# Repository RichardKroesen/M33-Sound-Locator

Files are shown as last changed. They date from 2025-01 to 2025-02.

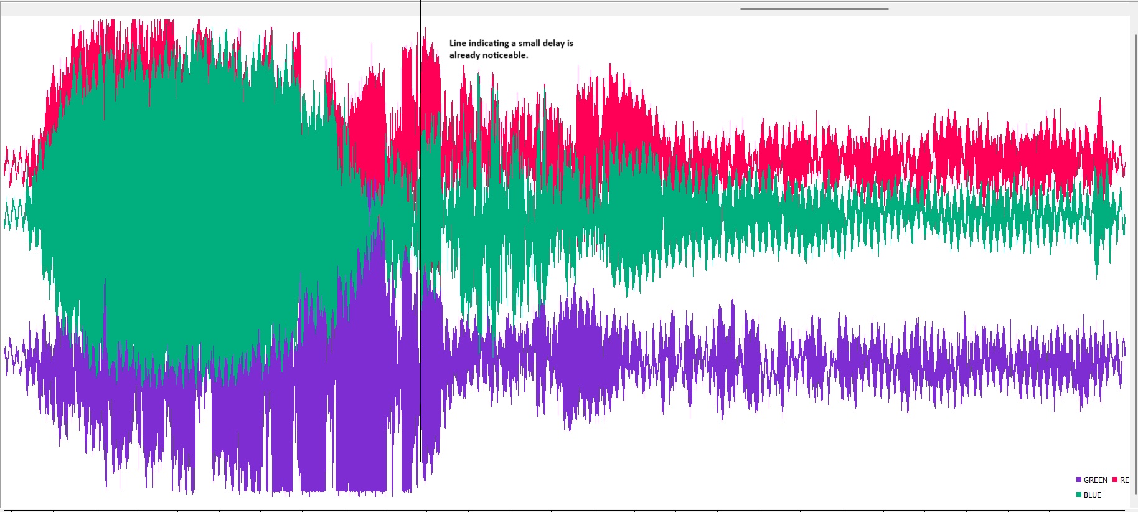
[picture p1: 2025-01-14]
docs/functional_testing/Delay_principle_verification.jpg

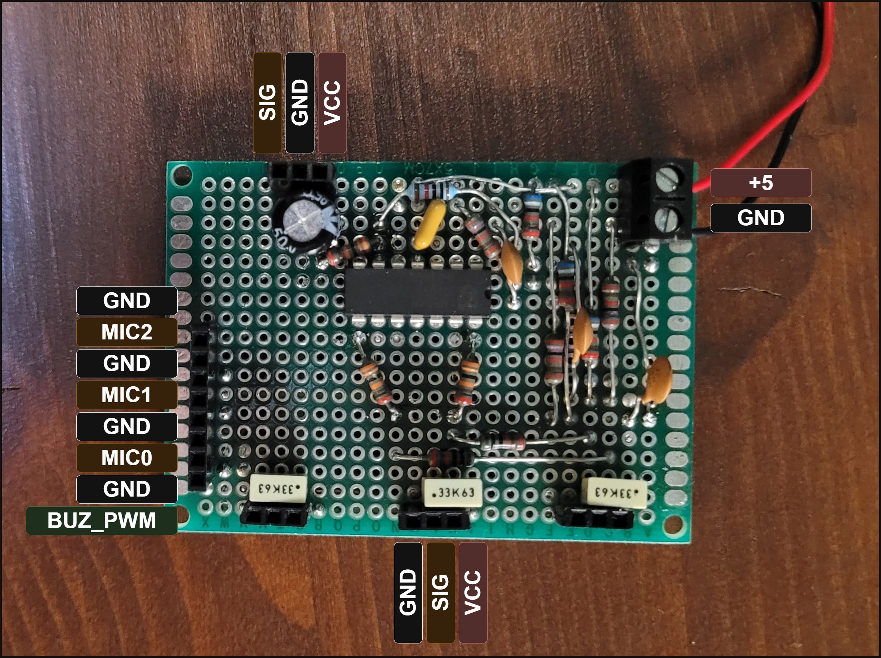
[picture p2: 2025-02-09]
docs/v1.0-PCB_pinout.jpg

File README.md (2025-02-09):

# Sound Locator M33 
This project has an educational purpose in the context of Digital Signal Processing & Control Systems. It is part of the Linear Systems (5LIU0)course at Technical University Eindhoven (TUe).

*The project's problem definition is*: 
> The challenge lies in accurately localizing a sound source on a two-dimensional plane
in real-time using audio pulses of a predefined frequency.
This involves addressing limitations in real-time processing, noise interference, and
the computational constraints of embedded systems while designing and implementing an effective DSP algorithm.

In more practical sense, it's a real-time processing system which locates the buzzer on a 2D plane. 

## Getting Started
**Clone by**: 

``git clone --recurse-submodules git@github.com:RichardKroesen/M33-Sound-Locator.git``

**Building Steps**: 
- mkdir build
- cmake ..
- make -j4

**Flashing steps**
Make sure the device is in BOOTSEL mode, this can be done by pressing the BOOTSEL button on the Pico. Afterwards there are two methods of uploading the file:

1. Using file explorer

Simply use a file explorer to drag the .uf2 file into the memory of the pico.

2. Using picotool

It is also possible to flash the device using picotool, type the command down below to flash using the picotool. This command assumes you are in the root of the project. NOT in the build folder!

`picotool load -u -v -x -t elf build/src/LINEAR_SYSTEMS.elf`

## Prerequisites 
For proper usage of this repository the following things are needed: 
- CMake
- PicoSDK (if it is not properly automatically build with CMake configuration).
- Arm GCC Compiler: [download page](https://developer.arm.com/downloads/-/gnu-rm)
- libusb [download page](https://libusb.info/)
- For debugging J-Link: [weblink](https://www.segger.com/downloads/jlink/) 
 
Or use on Linux the following command:
`sudo apt install cmake python3 g++ build-essential ninja-build`
installing the Arm GCC compiler (the hard way)
1) ```wget https://developer.arm.com/-/media/Files/downloads/gnu/14.2.rel1/binrel/arm-gnu-toolchain-14.2.rel1-x86_64-arm-none-eabi.tar.xz```
2) ```tar -xvf arm-gnu-toolchain-14.2.rel1-x86_64-arm-none-eabi.tar.xz```
3) Move to a common location: ```sudo mv arm-gnu-toolchain-14.2.rel1-x86_64-arm-none-eabi /opt/```
4) Add to path: ```export PATH=$PATH:/opt/arm-gnu-toolchain-14.2.rel1-x86_64-arm-none-eabi/bin```
5) For Pico SDK: ```export PICO_TOOLCHAIN_PATH=/opt/arm-gnu-toolchain-14.2.rel1-x86_64-arm-none-eabi``` and ```export PATH=$PICO_TOOLCHAIN_PATH/bin:$PATH```

## Troubleshooting 
Since in our project group everyone is working on a different system there could be some compilation issues. In this section the most common issues are documented for quick reference. 

- CMake Error at build/_deps/pico_sdk-src/cmake/preload/toolchains/util/find_compiler.cmake:29 (message):
  Compiler 'arm-none-eabi-gcc' not found, you can specify search path with
  "PICO_TOOLCHAIN_PATH". ==> Repeating step 5 seems to fix this issue. 

After you cloned load the submodules properly:
``git submodule update --init`` 

## Project state
This repository contains the development and implementation of a real-time sound source localization system. The project integrates signal processing, embedded systems, and hardware design for accurate 2D localization.

Current version is contains an embedded codebase which is used as data logging acquisition. And then manually feeding these logs into model scripts so that system evaluation is feasible. The intent is to finalize this project someday as a hobby, but for now it is released for the course finalization. 

### Finalization Steps
- Implement TDOA algorithm on the embedded device => Python model conversion
- Integrate key signal processing features:
  - Target signal validation
  - Time Difference of Arrival (TDOA) estimation
  - Final system testing
- Produce a refined PCB design with:
  - Active bandpass filter
  - Variable amplifier
  - Stable reference voltage and improved grounding

### Lessons Learned
- Peak-based TDOA derivation is unreliable.
- Buzzers produce unsuitable waveforms for processing.
- Batch sampling introduces artifacts affecting analysis.
- Data transmission adds timing constraints but is irrelevant in a fully embedded system.

### Solutions Provided
- Designed PCB with anti-aliasing filter and amplifier.
- Developed real-time ADC DMA-based batch sampling (FreeRTOS).
- Implemented cross-correlation-based TDOA estimation.
- Achieved millimeter-precision real-time localization.
- Optimized target sound source detection using CMSIS-DSP.
- Provided insights for future improvements and finalization.

### Optimalization 
- Remove virtual interface implementation, which really not optimal and determinalistic approach. But it made prototyping convenient, the recommendation is to introduce curiously recurring template design pattern (CRTP), which makes polymorphism more determinalistic than currently. 
- For an even more enhancement dual-core functionally could be utilized for handling the ADC DMA on one core and the processing on the other. 
- ADC DMA logging and control is currently not efficient, since ASCII characters are send over instead of raw bytes. Besides the fact that the ADC also is blocked for around 20 ms (calculations are in our project report under appendix 1) before it can continue (we decided to keep it like this for simplicity and it worked well enough for our experimentation purpose). 

## Acknowledgements 
It is only fair to credit resources which inspired or gave an excellent example which already existed.

Our cmake FreeRTOS configuration is inspired by Dr. Jon Durrant, from [this repository](https://github.com/jondurrant/RPIPicoFreeRTOSSMPExp). 

Besides the Raspberry Pi Pico repository of FreeRTOS porting helped out, especially for RP2350 there were some troubles which are already described in the issues-list.

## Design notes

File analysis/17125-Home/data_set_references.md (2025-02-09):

batch_buffer_size = 600 samples, so each channel takes 600 samples before DMA IRQ. 
F sampling = 500 kHz => 500k/3 for each channel 

Buzzer tone = 4000 hz
Buzzer volume: 40 % duty 
Buzzer width: 100 ms

Build: release commit: buzzer branch

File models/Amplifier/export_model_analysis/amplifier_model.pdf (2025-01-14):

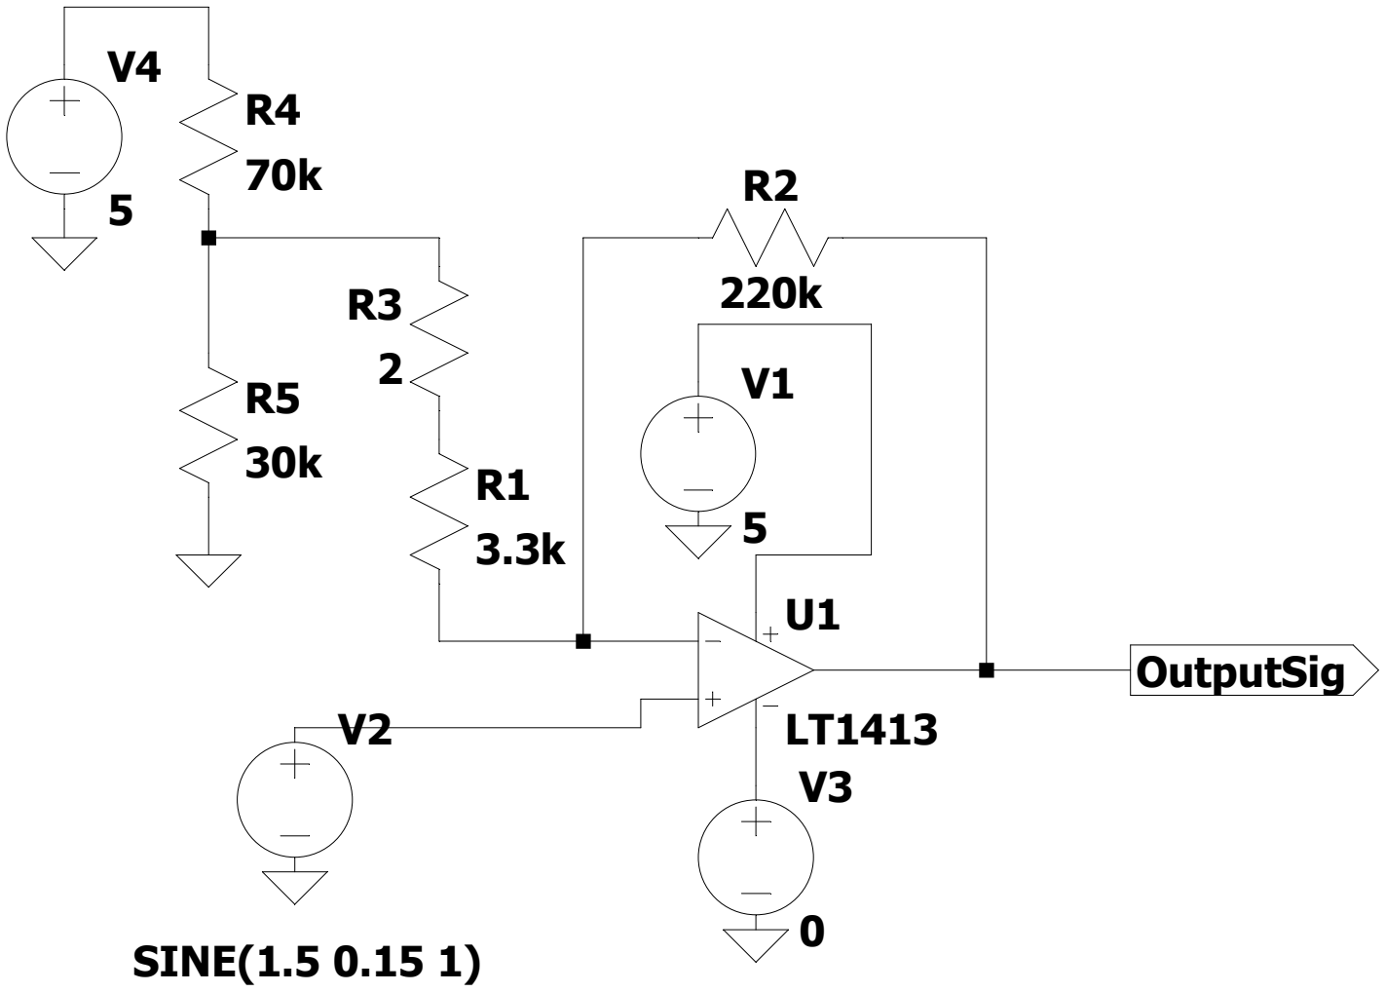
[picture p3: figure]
SINE(1.5 0.15 1); OutputSig

.tran 10

--- C:\_2025-Dev\2-Hardware\AmplifierModel.asc ---

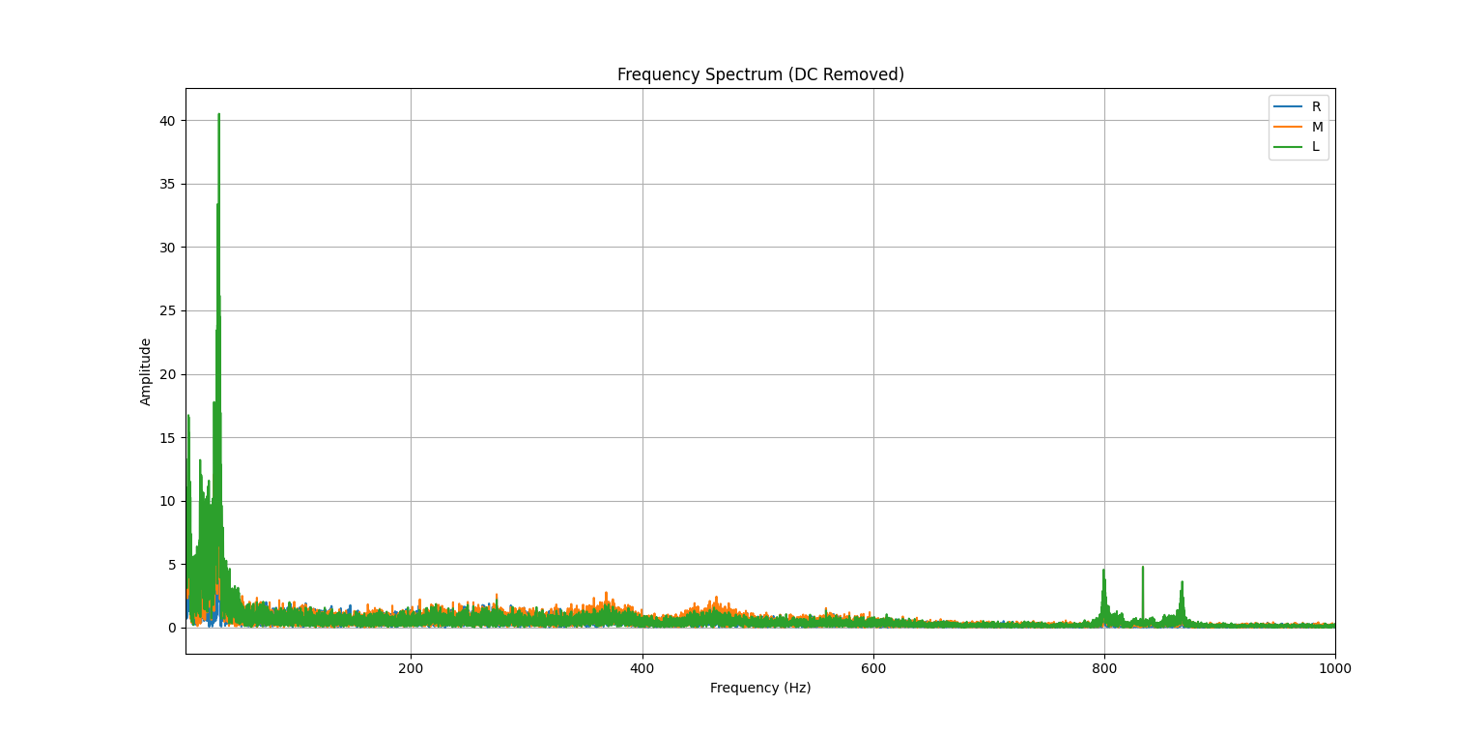
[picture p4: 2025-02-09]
analysis/insights/NoiseSpectrum.png

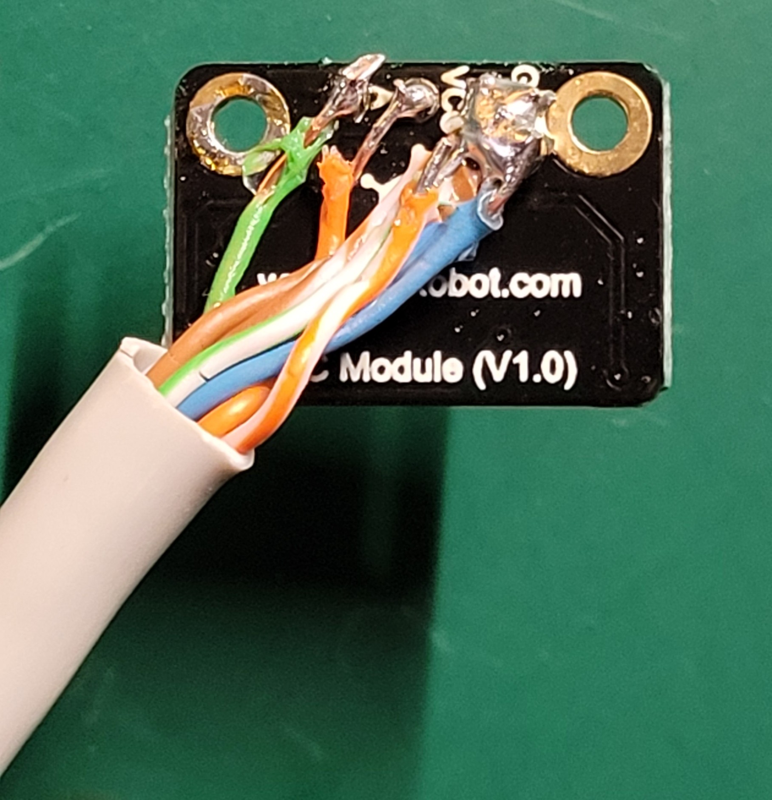
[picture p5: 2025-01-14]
electrical-mechnical-rsc/microphone-connection_pinout.jpg

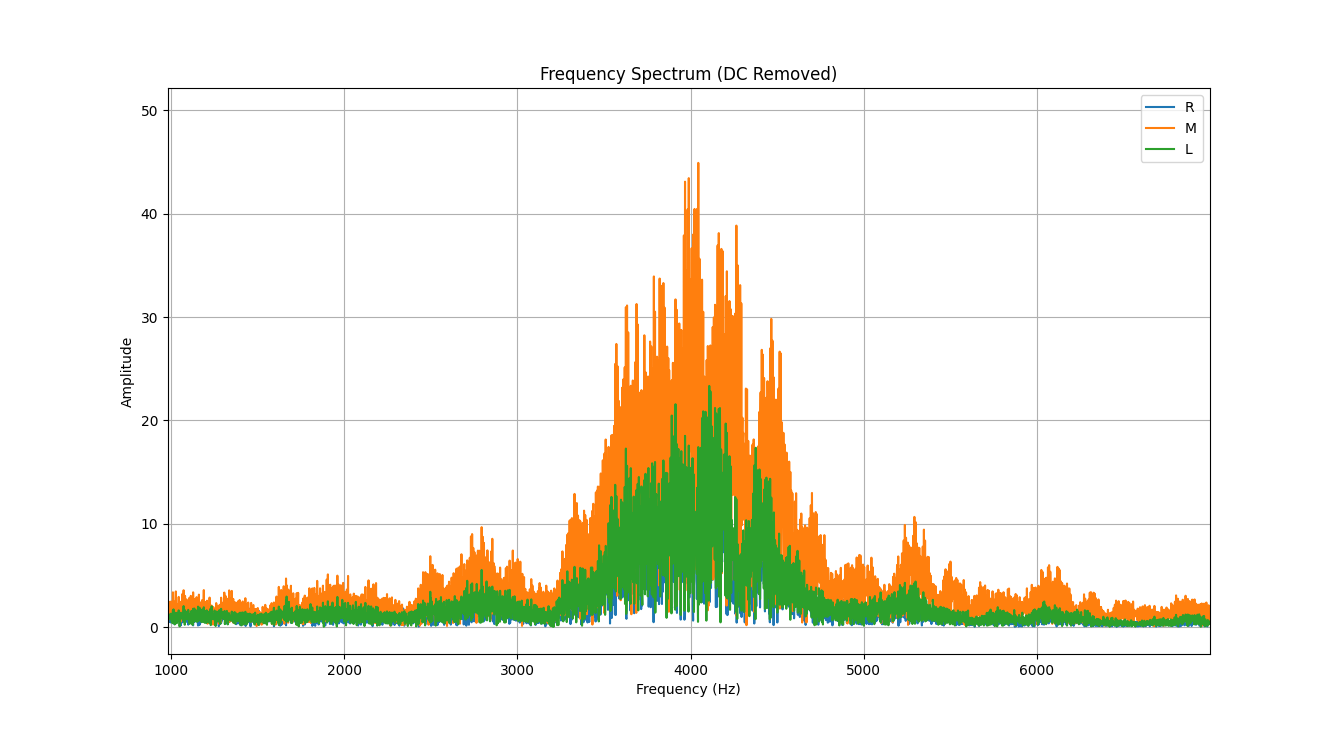
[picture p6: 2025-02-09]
analysis/insights/SW_FIR_spectrum_optimal_fcent4k-BW5-tps51.png

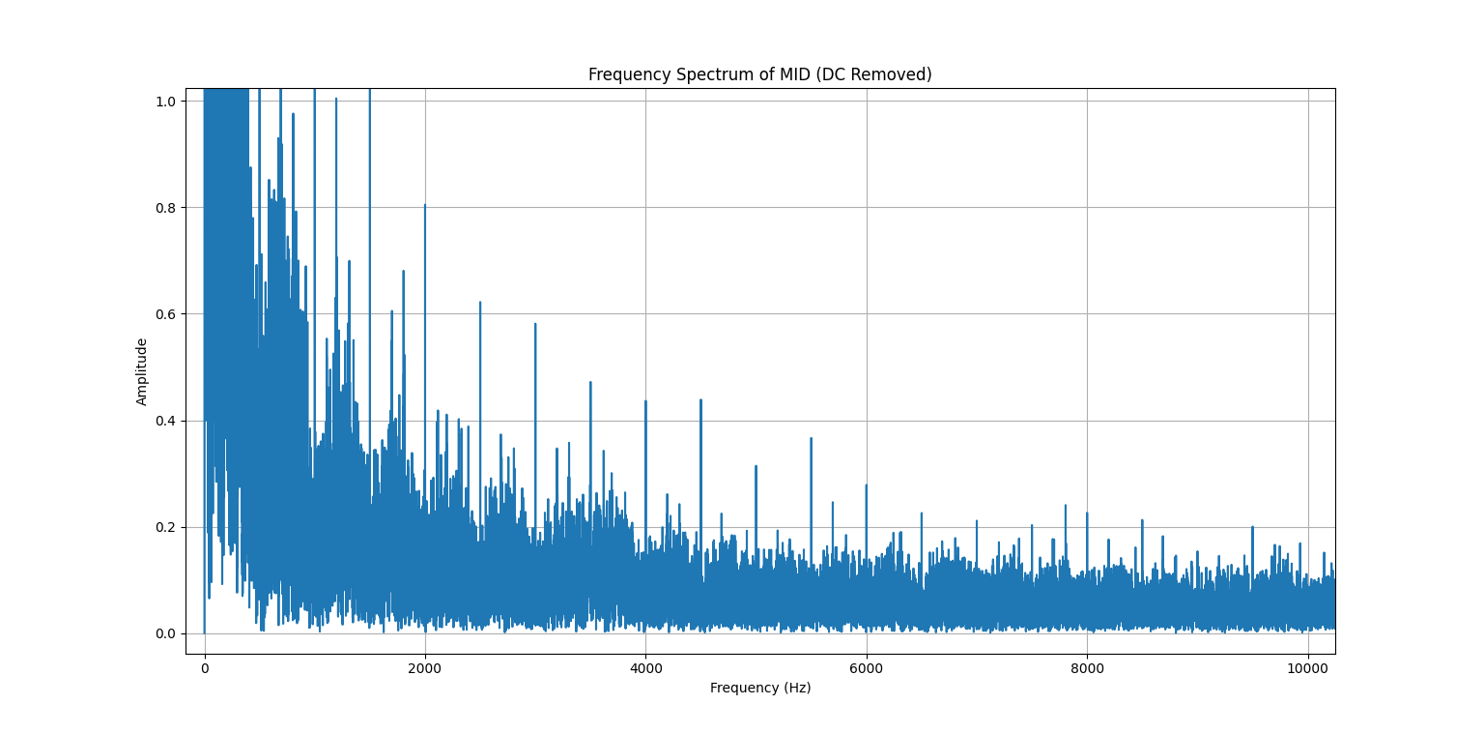
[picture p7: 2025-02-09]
analysis/insights/BeforeHW-LPF.png

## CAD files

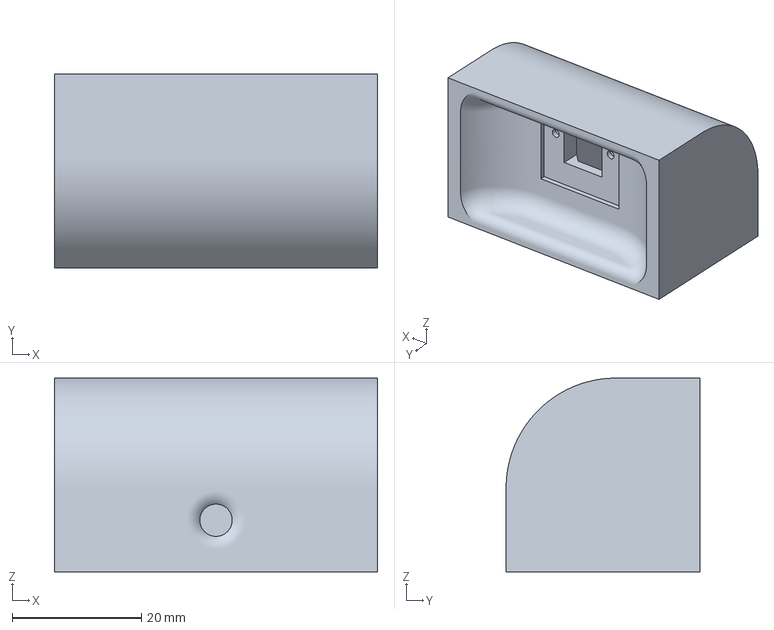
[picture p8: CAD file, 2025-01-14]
electrical-mechnical-rsc/production-3D_printing/v2-0_microphone-holder.3mf
50.0 x 30.0 x 30.0 mm

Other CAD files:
electrical-mechnical-rsc/microphone_holder/TUe2425_M33-SL-MicrophoneHolder v2.f3d
electrical-mechnical-rsc/production-3D_printing/v2-0_microphone-holder.stl

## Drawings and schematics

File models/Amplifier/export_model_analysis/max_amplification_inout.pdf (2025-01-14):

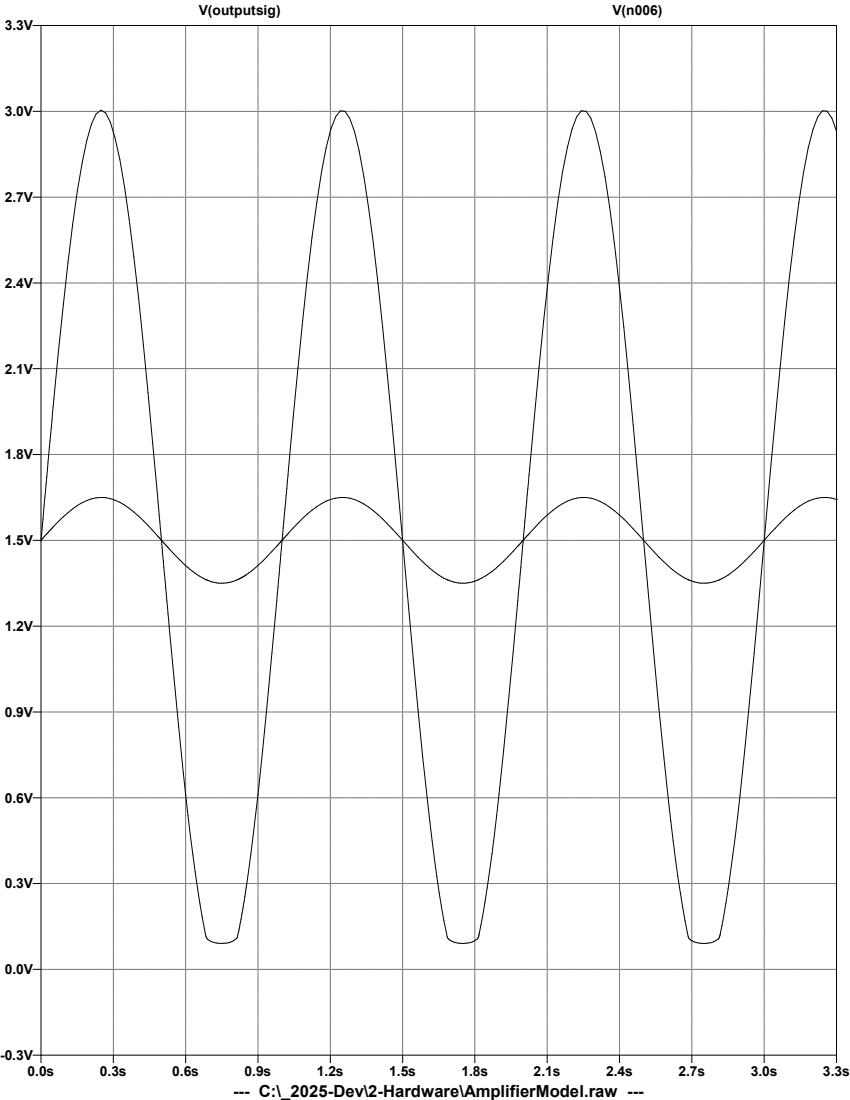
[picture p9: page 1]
V(outputsig)

--- C:\_2025-Dev\2-Hardware\AmplifierModel.raw ---

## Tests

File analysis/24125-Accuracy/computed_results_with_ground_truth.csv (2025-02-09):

Filename | True_X | True_Y | Computed_X | Computed_Y | Error_X | Error_Y
P0x50.csv | 0 | 50 | 13.0254089150135 | 43.7621621353552 | 13.0254089150135 | 6.23783786464484
P20x35.csv | 20 | 35 | 18.8566675756327 | 36.1853075102173 | 1.14333242436732 | 1.18530751021729
P20x50.csv | 20 | 50 | 25.653627396904 | 47.1661870387485 | 5.65362739690403 | 2.83381296125145
P20x60.csv | 20 | 60 | 27.9713615517674 | 50.0445178501976 | 7.97136155176736 | 9.95548214980237
P25x-5.csv | 25 | -5 | 21.7248352105727 | -1.96119868246716 | 3.27516478942733 | 3.03880131753284
P25x0.csv | 25 | 0 | 22.7494783336541 | -1.80059470858845 | 2.25052166634586 | 1.80059470858845
P25x25.csv | 25 | 25 | 24.71224721599 | 24.8548743934159 | 0.287752784010017 | 0.145125606584056
P25x50.csv | 25 | 50 | 31.528019254587 | 42.9137475274267 | 6.52801925458703 | 7.08625247257334
P45x5.csv | 45 | 5 | 45.964054654138 | 0.92731893840942 | 0.964054654138032 | 4.07268106159058
P55x-5.csv | 55 | -5 | 44.3404220984167 | 2.06724055071807 | 10.6595779015833 | 7.06724055071806

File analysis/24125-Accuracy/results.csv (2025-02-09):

Filename | Leading Signal | Phase Shift (MID) | Phase Shift (LEFT) | Phase Shift (RIGHT)
P0x50.csv | LEFT | -0.000582 |  | -0.00024
P20x35.csv | LEFT | -0.000402 |  | -0.00019800000000000002
P20x50.csv | LEFT | -0.00084 |  | -0.000858
P20x60.csv | LEFT | -0.00096 |  | -0.001038
P25x-5.csv | RIGHT | -0.000192 | -0.001098
P25x0.csv | RIGHT | -0.000132 | -0.0010500000000000002
P25x25.csv | RIGHT | -1.2e-05 | -1.8e-05
P25x50.csv | LEFT | -0.0007920000000000001 |  | -0.000984
P45x5.csv | MID |  | -0.0013260000000000001 | -0.00123
P55x-5.csv | MID |  | -0.001242 | -0.001128

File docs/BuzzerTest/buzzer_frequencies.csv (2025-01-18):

Time [s] | SW | BUZ
0.000000000 | 1 | 0
2.387693562 | 0 | 0
2.387697063 | 1 | 0
2.387786750 | 0 | 0
2.387840125 | 1 | 0
2.387840188 | 0 | 0
2.387843500 | 1 | 0
2.387843563 | 0 | 0
2.387843875 | 1 | 0
2.387844438 | 0 | 0
2.387845500 | 1 | 0
2.387845562 | 0 | 0
2.387845813 | 1 | 0
2.387846500 | 0 | 0
2.387846688 | 1 | 0
2.387847938 | 0 | 0
2.387858250 | 1 | 0
2.387858313 | 0 | 0
2.387908187 | 1 | 0
2.387916375 | 0 | 0
2.387932688 | 1 | 0
2.387932812 | 0 | 0
2.387936375 | 1 | 0
2.387936438 | 0 | 0
2.387940313 | 1 | 0
2.387940375 | 0 | 0
2.387949375 | 1 | 0
2.387949500 | 0 | 0
2.387960250 | 1 | 0
2.387960500 | 0 | 0
2.387964312 | 1 | 0
2.387964812 | 0 | 0
2.388106625 | 0 | 1
2.389108125 | 0 | 0
2.390107813 | 0 | 1
2.391109375 | 0 | 0
2.392109062 | 0 | 1
2.393110625 | 0 | 0
2.394110313 | 0 | 1
2.395111875 | 0 | 0
2.396111562 | 0 | 1
2.397113062 | 0 | 0
2.398112812 | 0 | 1
2.399114313 | 0 | 0
2.400114000 | 0 | 1
2.401115562 | 0 | 0
2.402115250 | 0 | 1
2.403116812 | 0 | 0
2.404116500 | 0 | 1
2.405118000 | 0 | 0
2.406117750 | 0 | 1
2.407119250 | 0 | 0
2.408118937 | 0 | 1
2.409120500 | 0 | 0
2.410120188 | 0 | 1
2.411121750 | 0 | 0
2.412121438 | 0 | 1
2.413122937 | 0 | 0
2.414122687 | 0 | 1
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

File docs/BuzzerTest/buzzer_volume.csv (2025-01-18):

Time [s] | SW | BUZ
0.000000000 | 1 | 0
2.781900938 | 0 | 0
2.781905688 | 1 | 0
2.781905812 | 0 | 0
2.781906625 | 1 | 0
2.781920937 | 0 | 0
2.781960188 | 1 | 0
2.781960875 | 0 | 0
2.782161312 | 0 | 1
2.783162813 | 0 | 0
2.784162500 | 0 | 1
2.785164062 | 0 | 0
2.786163750 | 0 | 1
2.787165250 | 0 | 0
2.788165000 | 0 | 1
2.789166500 | 0 | 0
2.790166250 | 0 | 1
2.791167750 | 0 | 0
2.792167437 | 0 | 1
2.793169000 | 0 | 0
2.794168688 | 0 | 1
2.795170250 | 0 | 0
2.796169938 | 0 | 1
2.797171437 | 0 | 0
2.798171187 | 0 | 1
2.799172688 | 0 | 0
2.800172375 | 0 | 1
2.801173938 | 0 | 0
2.802173625 | 0 | 1
2.803175187 | 0 | 0
2.804174875 | 0 | 1
2.805176375 | 0 | 0
2.806176125 | 0 | 1
2.807177625 | 0 | 0
2.808177375 | 0 | 1
2.809178875 | 0 | 0
2.810178562 | 0 | 1
2.811180125 | 0 | 0
2.812179813 | 0 | 1
2.813181375 | 0 | 0
2.814181062 | 0 | 1
2.815182562 | 0 | 0
2.816182313 | 0 | 1
2.817183813 | 0 | 0
2.818183500 | 0 | 1
2.819185062 | 0 | 0
2.820184750 | 0 | 1
2.821186313 | 0 | 0
2.822186000 | 0 | 1
2.823187562 | 0 | 0
2.824187250 | 0 | 1
2.825188875 | 0 | 0
2.826188500 | 0 | 1
2.827190000 | 0 | 0
2.828189688 | 0 | 1
2.829191250 | 0 | 0
2.830190937 | 0 | 1
2.831192500 | 0 | 0
2.832192188 | 0 | 1
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

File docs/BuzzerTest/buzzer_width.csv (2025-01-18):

Time [s] | SW | BUZ
0.000000000 | 1 | 0
4.627967437 | 0 | 0
4.627967500 | 1 | 0
4.627972687 | 0 | 0
4.627993812 | 1 | 0
4.627994500 | 0 | 0
4.627998188 | 1 | 0
4.627998250 | 0 | 0
4.628002375 | 1 | 0
4.628002562 | 0 | 0
4.628002688 | 1 | 0
4.628016125 | 0 | 0
4.628018875 | 1 | 0
4.628096875 | 0 | 0
4.628099375 | 1 | 0
4.628099500 | 0 | 0
4.628101313 | 1 | 0
4.628110937 | 0 | 0
4.628179688 | 1 | 0
4.628179750 | 0 | 0
4.628181438 | 1 | 0
4.628181563 | 0 | 0
4.628184812 | 1 | 0
4.628184875 | 0 | 0
4.628192500 | 1 | 0
4.628192688 | 0 | 0
4.628205187 | 1 | 0
4.628205250 | 0 | 0
4.628224500 | 1 | 0
4.628226125 | 0 | 0
4.628234687 | 1 | 0
4.628238687 | 0 | 0
4.628238750 | 1 | 0
4.628241375 | 0 | 0
4.628267187 | 1 | 0
4.628267313 | 0 | 0
4.628269375 | 1 | 0
4.628272188 | 0 | 0
4.628282937 | 1 | 0
4.628304500 | 0 | 0
4.628366500 | 1 | 0
4.628366625 | 0 | 0
4.628522500 | 0 | 1
4.628550000 | 1 | 1
4.628551437 | 0 | 1
4.628609875 | 1 | 1
4.628611250 | 0 | 1
4.628625500 | 1 | 1
4.628625687 | 0 | 1
4.628644125 | 1 | 1
4.628657312 | 0 | 1
4.628661750 | 1 | 1
4.628662438 | 0 | 1
4.628702438 | 1 | 1
4.628714125 | 0 | 1
4.628815562 | 1 | 1
4.628815688 | 0 | 1
4.628815750 | 1 | 1
4.628816063 | 0 | 1
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

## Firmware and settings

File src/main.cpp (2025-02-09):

/** MIT License
 * 
 * Copyright (c) 2025 Feb. by Julian Bruin, James Schutte, Richard Kroesen
 * 
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
 * THE SOFTWARE IS PROVIDED "AS IS", WITHOUT WARRANTY OF ANY KIND, EXPRESS OR
 * IMPLIED, INCLUDING BUT NOT LIMITED TO THE WARRANTIES OF MERCHANTABILITY,
 * FITNESS FOR A PARTICULAR PURPOSE AND NONINFRINGEMENT. IN NO EVENT SHALL THE
 * AUTHORS OR COPYRIGHT HOLDERS BE LIABLE FOR ANY CLAIM, DAMAGES OR OTHER
 * LIABILITY, WHETHER IN AN ACTION OF CONTRACT, TORT OR OTHERWISE, ARISING FROM,
 * OUT OF OR IN CONNECTION WITH THE SOFTWARE OR THE USE OR OTHER DEALINGS IN THE
 * SOFTWARE.
 */

#include "main.hpp"

template <const size_t NUM_TASKS>
static inline void vLaunch() {
	BaseType_t xReturned[NUM_TASKS];
	TaskHandle_t taskHandle[NUM_TASKS];

    xReturned[0] = xTaskCreate(heart_beat_task, 
		"Heartbeat", 
		configMINIMAL_STACK_SIZE, 
		NULL, tskIDLE_PRIORITY, &taskHandle[0]);

	xReturned[1] = xTaskCreate(trigger_buz_on_button_task,
		"BuzzerTrigger", 
		configMINIMAL_STACK_SIZE, 
		NULL, configMAX_PRIORITIES-2, &taskHandle[1]);

	// Check the tasks are created, otherwise delete them:
	for (size_t i = 0; i < NUM_TASKS; i++) {
		if (xReturned[i] != pdPASS) {
			vTaskDelete(taskHandle[i]);
		}
	}

    /* Start the tasks and timer running. */
    vTaskStartScheduler();
}

int main() {
	/* Setup */
	stdio_init_all();
	vLaunch<1>();

    for (;;) {}
	return 1;
}

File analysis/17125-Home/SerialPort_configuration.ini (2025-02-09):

[MainWindow]
size=@Size(1680 961)
pos=@Point(-1681 21)
activePanel=Plot
hidePanels=false
maximized=true
state=@ByteArray(\0\0\0\xff\0\0\0\0\xfd\0\0\0\0\0\0\x6\x90\0\0\x3\x66\0\0\0\x4\0\0\0\x4\0\0\0\b\0\0\0\b\xfc\0\0\0\x1\0\0\0\x2\0\0\0\x3\0\0\0\f\0t\0\x62\0P\0l\0o\0t\x1\0\0\0\0\xff\xff\xff\xff\0\0\0\0\0\0\0\0\0\0\0\x1a\0t\0\x62\0P\0o\0r\0t\0\x43\0o\0n\0t\0r\0o\0l\x1\0\0\0}\xff\xff\xff\xff\0\0\0\0\0\0\0\0\0\0\0\x10\0t\0\x62\0R\0\x65\0\x63\0o\0r\0\x64\x1\0\0\x1\xd8\xff\xff\xff\xff\0\0\0\0\0\0\0\0)

[Port]
selectedPort=COM8
baudRate=256000
parity=none
dataBits=8
stopBits=1
flowControl=none

[DataFormat]
format=ascii

[DataFormat_Binary]
numOfChannels=1
numberFormat=uint16
endianness=little

[DataFormat_ASCII]
numOfChannels=3
delimiter=","
customDelimiter=" "
filterMode=disabled
filterPrefix=

[DataFormat_CustomFrame]
numOfChannels=1
numberFormat=uint8
endianness=little
frameStart=AA BB
fixedSize=false
frameSize=1
checksum=false
debugMode=false

[Channels]
channel\1\name=LEFT
channel\1\color=@Variant(\0\0\0\x43\x1\xff\xff\xff\xff\0\0VV\0\0)
channel\1\visible=true
channel\1\gain=1
channel\1\gainEnabled=false
channel\1\offset=-230
channel\1\offsetEnabled=false
channel\2\name=RIGHT
channel\2\color=@Variant(\0\0\0\x43\x1\xff\xff~~--\xd2\xd2\0\0)
channel\2\visible=true
channel\2\gain=0.7
channel\2\gainEnabled=false
channel\2\offset=470
channel\2\offsetEnabled=false
channel\3\name=MID
channel\3\color=@Variant(\0\0\0\x43\x1\xff\xff\0\0\xae\xae~~\0\0)
channel\3\visible=true
channel\3\gain=1
channel\3\gainEnabled=false
channel\3\offset=0
channel\3\offsetEnabled=false
channel\4\name=STRENGTH
channel\4\color=@Variant(\0\0\0\x43\x1\xff\xff\xfe\xfe\x89\x89\0\0\0\0)
channel\4\visible=true
channel\4\gain=1
channel\4\gainEnabled=false
channel\4\offset=0
channel\4\offsetEnabled=false
channel\5\name=Channel 5
channel\5\color=@Variant(\0\0\0\x43\x1\xff\xff\xff\xff\x93\x93~~\0\0)
channel\5\visible=true
channel\5\gain=1
channel\5\gainEnabled=false
channel\5\offset=0
channel\5\offsetEnabled=false
channel\size=5

[Plot]
numOfSamples=100000
plotWidth=100000
indexAsX=true
xMax=1000
xMin=0
autoScale=false
yMax=4250
yMin=0
darkBackground=false
grid=true
minorGrid=true
legend=true
multiPlot=false
symbols=auto
numLines=1000
decimals=0

[Commands]
command\1\name=Command 1
command\1\type=ascii
command\1\data=
command\2\name=Command 2
command\2\type=ascii
command\2\data=
command\size=2

[Record]
autoIncrement=true
recordPaused=true
stopOnClose=true
header=true
disableBuffering=false
separator=","
decimals=6
timestamp=false
timestampFormat=seconds

[UpdateCheck]
periodicCheck=true
lastCheck=2025-01-17

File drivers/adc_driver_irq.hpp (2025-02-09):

/** MIT License
 * 
 * Copyright (c) 2025 Feb. by Julian Bruin, James Schutte, Richard Kroesen
 * 
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
 * THE SOFTWARE IS PROVIDED "AS IS", WITHOUT WARRANTY OF ANY KIND, EXPRESS OR
 * IMPLIED, INCLUDING BUT NOT LIMITED TO THE WARRANTIES OF MERCHANTABILITY,
 * FITNESS FOR A PARTICULAR PURPOSE AND NONINFRINGEMENT. IN NO EVENT SHALL THE
 * AUTHORS OR COPYRIGHT HOLDERS BE LIABLE FOR ANY CLAIM, DAMAGES OR OTHER
 * LIABILITY, WHETHER IN AN ACTION OF CONTRACT, TORT OR OTHERWISE, ARISING FROM,
 * OUT OF OR IN CONNECTION WITH THE SOFTWARE OR THE USE OR OTHER DEALINGS IN THE
 * SOFTWARE.
 */

#ifndef ADC_DRIVER__IRQ_HPP
#define ADC_DRIVER__IRQ_HPP

#include <math.h>
#include "FreeRTOS.h"
#include "task.h"
#include "stream_buffer.h"
#include "hardware/gpio.h"
#include "hardware/adc.h"

#include "system_references.hpp"
#include <adc_driver_interface.hpp>

namespace ADC {

template<const ADC_FREQUENCIES SAMPLE_RATE, 
uint32_t CHANNEL_BUFFER_SAMPLES_SIZE = 300,
uint32_t BATCH_BUFFER_SIZE = CHANNEL_BUFFER_SAMPLES_SIZE,
const uint8_t CHANNELS = 3>

class ADC_Driver : public IADC_Driver<SAMPLE_RATE, CHANNEL_BUFFER_SAMPLES_SIZE, BATCH_BUFFER_SIZE, CHANNELS> {
    
    using IADC = IADC_Driver<SAMPLE_RATE, CHANNEL_BUFFER_SAMPLES_SIZE, BATCH_BUFFER_SIZE, CHANNELS>; // Alias for convenience

public: 
    ADC_Driver() {
        static_assert(static_cast<uint32_t>(SAMPLE_RATE) > 0, "Err sample rate cannot be 0");
        static_assert(CHANNELS < 5, "Err not possible to select more than 4 channels.");
        init();
    }

    ~ADC_Driver() {
        if (stream_buffer != nullptr) {
            vStreamBufferDelete(stream_buffer);
        }
    }

    const bool start_adc() override {
        return start_adc_static();
    }

    void stop_adc() override {
        stop_adc_static();
    }

    void set_notification_task(const TaskHandle_t task) override {
        this->notificationTask = task;
    }

    void copy_buffer(std::unique_ptr<uint16_t[]>& destination, const size_t size) override {
        taskENTER_CRITICAL(); 
        xStreamBufferReceive(stream_buffer, destination.get(), size * sizeof(uint16_t), 0);
        taskEXIT_CRITICAL();
    }
    
protected:
    const static inline bool start_adc_static() {
        if (init_flag) {
            adc_run(false);
            adc_fifo_drain();

            adc_select_input(IADC::pin_references[0].adc_reference); // Initial Channel. 
            adc_irq_set_enabled(true);
            irq_set_enabled(ADC_IRQ_FIFO, true);
            adc_run(true);
            return true;
        }
        return false; 
    }

    static inline void stop_adc_static() {
        adc_run(false);
        adc_fifo_drain();
        
        adc_irq_set_enabled(false);
        irq_set_enabled(ADC_IRQ_FIFO, false);

        xStreamBufferReset(stream_buffer);
    }
    
private: 
    constexpr static size_t STREAM_BUFFER_B_SIZE  = CHANNEL_BUFFER_SAMPLES_SIZE * sizeof(uint16_t); // Size in bytes
    constexpr static size_t TRIGGER_LEVEL = 201;                                       // Minimum bytes to wake a task
    constexpr static inline uint32_t clk_divider = IADC::compute_clk_divider();

    static inline StreamBufferHandle_t stream_buffer = {nullptr};
    static inline TaskHandle_t notificationTask = nullptr;

    static inline bool init_flag = false;

    static inline void init() {
        if (! init_flag) {
            uint16_t adc_channels_mask = 0x0000;
            adc_init();

            stream_buffer = xStreamBufferCreate(STREAM_BUFFER_B_SIZE, TRIGGER_LEVEL);
            configASSERT(stream_buffer != nullptr);

            for (size_t i = 0; i < CHANNELS; i++) {
                gpio_set_dir(IADC::pin_references[i].pin, false);
                gpio_disable_pulls(IADC::pin_references[i].pin);
                adc_gpio_init(IADC::pin_references[i].pin);
            }

            for (uint8_t i = 0; i < CHANNELS; i++) {
                adc_channels_mask |= (1 << IADC::pin_references[i].adc_reference);
            }

            adc_set_round_robin(adc_channels_mask);
            adc_fifo_setup(
                true,
                false,
                CHANNELS,
                false,
                false
            );								
            
            irq_set_exclusive_handler(ADC_IRQ_FIFO, adc_handler);
            irq_set_priority (ADC_IRQ_FIFO, PICO_HIGHEST_IRQ_PRIORITY);		

            if (SAMPLE_RATE >= (ADC_FREQUENCIES::FS_MAX_PICO)) {
                adc_set_clkdiv(0); // Reload without interval, 500 MHz.
            } else {
                adc_set_clkdiv(clk_divider);
            }

            init_flag = true;
        }
    }

    // Execute only from RAM, because of critical timing: 
    static void __not_in_flash_func(adc_handler)(void) {
        if (! adc_fifo_is_empty()) {
            BaseType_t xHigherPriorityTaskWoken = pdFALSE;
            for (uint8_t i = 0; i < CHANNELS; i++) {
                uint16_t sample = adc_fifo_get();
                xStreamBufferSendFromISR(stream_buffer, 
                    &sample, sizeof(uint16_t), &xHigherPriorityTaskWoken);
            }
            portYIELD_FROM_ISR(xHigherPriorityTaskWoken);
        }
    } 
}; // ADC_DRIVER Class
}; // ADC Namespace
#endif /* ADC_DRIVER__IRQ_HPP */

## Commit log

2024-11-20 Add JLink debugging support; Tst the current setup is stable debugging works, FreeRTOS support is fine and the SDK.
2024-12-12 Add initial ADC sampling tryout. Just a quick play around and check of how the sdk works.
2024-12-14 Enh small cleanup and refactor, the adc functionality part is finalized. Only proper buffering is needed.
2024-12-18 Add improved ADC with verified buffering option.
2024-12-18 Add reset of buffer when adc is stopped.
2024-12-18 Add V2 mechanical model for microphone holder.
    [TUe2425_M33-SL-MicrophoneHolder v2.f3d, v2-0_microphone-holder.3mf, v2-0_microphone-holder.stl]
2024-12-21 Enh final commit on IRQ adc handling, I tried to optimize ADC handling by utilizing batching idea. However since in the end we would use IRQ I will pause this IRQ implementation because it is pointle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
2024-12-23 Add tested adc dma implementation, with max fs yey.
2024-12-23 Enh fixed a bug of initial channel values not aligned properly at start.
    [main.cpp]
2024-12-23 Fix the submodule in this branch.
    [main.cpp]
2024-12-23 Enh architectural refactoring to allow interfacing of IRQ or DMA implementation. Add improved IRQ based sampling.
2024-12-30 Add improved adc sampling, irq based works works only for 1k fs because each sample needs to be copied in the irq. The task never gets a chance above the fs because the irq are faster than freertos t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
2025-01-05 Add mic sample distribution setup.
2025-01-06 Enh finalized the ADC sampling setup.
2025-01-12 Fix clean up main.cpp
    [main.cpp]
2025-01-13 Add Sample processor to perform fft and detect dominant frequency
2025-01-13 Add Example in main with generated adc samples
2025-01-13 Fix migrated to CPP class style structure
    This looks better and more refined over the old, more C styled code
    Also makes previously constant variables dynamically changable
    [locator.hpp, main.cpp]
2025-01-13 Add final hardware documentation, design resources etc.
    [TUe2425_M33-SL-MicrophoneHolder v2.f3d]
2025-01-14 Enh bikeshedding complete
    No more bikeshedding
    We've solved world hunger
    [locator.hpp, main.cpp]
2025-01-15 Add buzzer and button drivers.
2025-01-15 Enh finalized and tested the buzzer and button detection.
    [buzzer_frequencies.csv, buzzer_volume.csv, buzzer_width.csv]
2025-01-17 Add dataset for experimental analysis.
    [BUZ-P15x60.csv, BUZ-P20x20.csv, BUZ-P20x60.csv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]
2025-01-17 Add FIR filter approach for clearcut filtering of the noise from our buggy HW.
    :
2025-01-18 Add software FIR filter simulation and model.
2025-01-18 Fix some merge inconsistencies.
    [main.cpp]
2025-01-20 Add PCB pinout for reference useage.
2025-01-25 Add last Friday's data set from measurements.
    [BUZ-P15x60.csv, BUZ-P20x20.csv, BUZ-P20x60.csv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]
2025-01-26 Add geometric accuracy measurement results.
    [computed_results_with_ground_truth.csv, results.csv]
